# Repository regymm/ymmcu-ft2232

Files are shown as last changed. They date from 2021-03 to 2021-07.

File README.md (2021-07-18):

## YMMCU-FT2232HL

#### Function

Can be used as Xilinx JTAG downloader & USB-to-UART bridge simultaneously following [this](https://gist.github.com/rikka0w0/24b58b54473227502fa0334bbe75c3c1). 

Partly pin-to-pin compatible with the CJMCU FT232HL(the purple PCB one) and has a standard 2x7 JTAG connector. 

Main chips: FT2232HL(QFP64), ASM1117(3.3V, SOT89), 93LC56(SOP8). 

Micro-USB + Type-C(tested later so not shown on pic) connection. 

Made with Kicad. 

#### Gallery

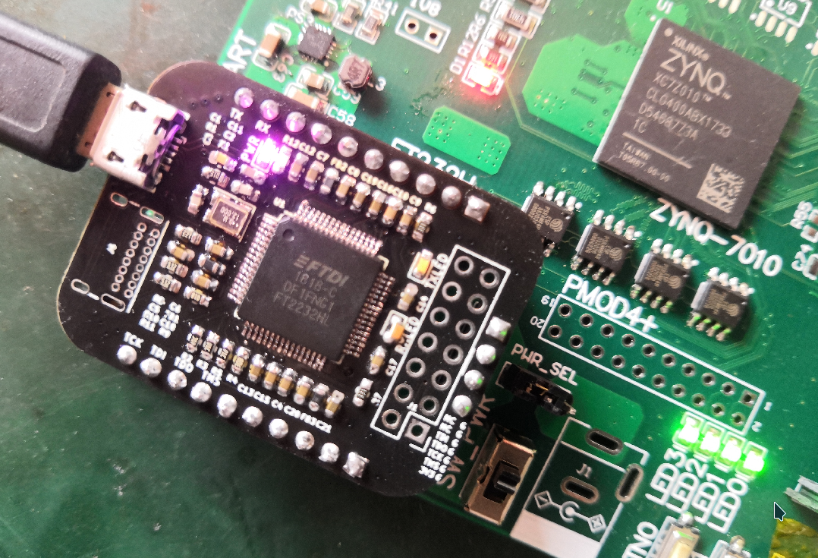
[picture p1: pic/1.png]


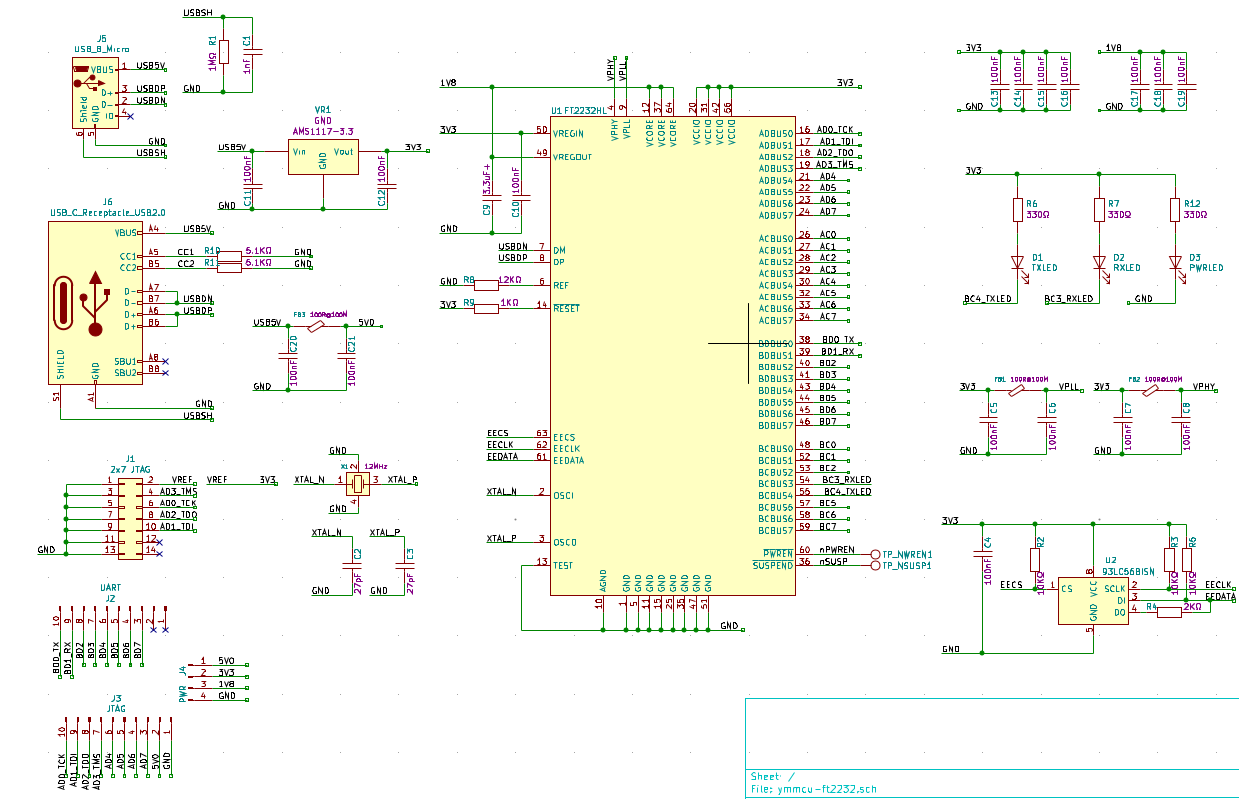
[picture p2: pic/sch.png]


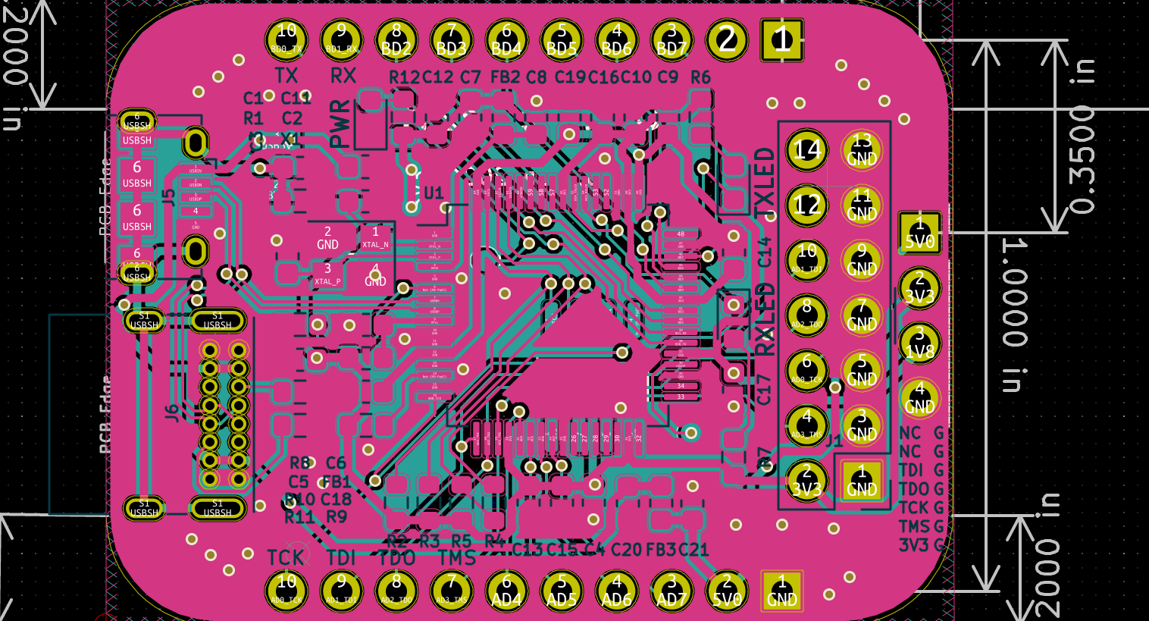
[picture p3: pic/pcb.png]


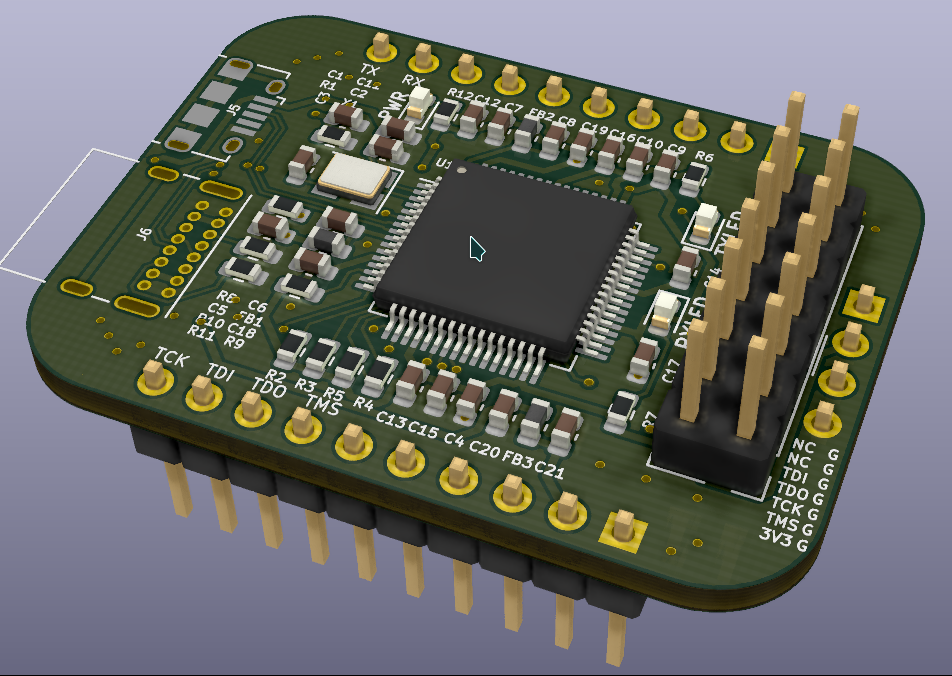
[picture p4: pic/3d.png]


#### License

GPL-v3

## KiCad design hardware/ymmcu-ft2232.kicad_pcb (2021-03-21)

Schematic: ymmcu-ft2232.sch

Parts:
C1: 0805_1nF__102_10%_50V; C_0603_1608Metric
C2, C3: 0805_27pF__270_5%_50V; C_0603_1608Metric
C4, C5, C6, C7, C8, C10, C11, C12, C13, C14, C15, C16, C17, C18, C19, C20, C21: 1206_100nF__104_10%_50V; C_0603_1608Metric
C9: 0805_3.3nF__332_10%_50V; C_0603_1608Metric
D1: TXLED; LED_0603_1608Metric
D2: RXLED; LED_0603_1608Metric
D3: PWRLED; LED_0603_1608Metric
FB1, FB2, FB3: FBEAD_SMD_BLM21PG221SN1D; L_0603_1608Metric
J1: 2x7 JTAG; PinHeader_2x07_P2.54mm_Vertical
J2: UART; PinHeader_1x10_P2.54mm_Vertical
J3: JTAG; PinHeader_1x10_P2.54mm_Vertical
J4: PWR; PinHeader_1x04_P2.54mm_Vertical
J5: USB_B_Micro; USB_Micro-B_Amphenol_10118194_Horizontal
J6: USB_C_Receptacle_USB2.0; USB_C_Receptacle_GCT_USB4085
R1: 0805_1MΩ__1004_1%; R_0603_1608Metric
R2, R3, R5: 1206_10KΩ__1002_1%; R_0603_1608Metric
R4: 1206_2KΩ__2001_1%; R_0603_1608Metric
R6, R7, R12: 0805_330Ω__3300_1%; R_0603_1608Metric
R8: 0805_12KΩ__1202_1%; R_0603_1608Metric
R9: 1206_1KΩ__1001_1%; R_0603_1608Metric
R10, R11: 0805_5.1KΩ__5101_1%; R_0603_1608Metric
TP_NSUSP1: TESTPOINT_SMD_C1; TestPoint_Pad_D1.0mm
TP_NWREN1: TESTPOINT_SMD_C1; TestPoint_Pad_D1.0mm
U1: FT2232HL; LQFP-64_10x10mm_P0.5mm
U2: 93LC56BISN; SOP-8_3.9x4.9mm_P1.27mm
VR1: SOT-223_AMS1117-3.3; SOT-223
X1: XTL_4_12MHz_3225; Crystal_SMD_3225-4Pin_3.2x2.5mm

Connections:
/1V8: C9.2, C17.2, C18.2, C19.2, J4.3, U1.12, U1.37, U1.49, U1.64
/3V3: C4.1, C5.1, C7.1, C10.2, C12.2, C13.2, C14.2, C15.2, C16.2, FB1.1, FB2.1, J1.2, J4.2, R2.1, R3.1, R5.1, R6.2, R7.2, R9.2, R12.2, U1.20, U1.31, U1.42, U1.50, U1.56, U2.8, VR1.2
/5V0: C21.1, FB3.2, J3.2, J4.1
/AD0_TCK: J1.6, J3.10, U1.16
/AD1_TDI: J1.10, J3.9, U1.17
/AD2_TDO: J1.8, J3.8, U1.18
/AD3_TMS: J1.4, J3.7, U1.19
/AD4: J3.6, U1.21
/AD5: J3.5, U1.22
/AD6: J3.4, U1.23
/AD7: J3.3, U1.24
/BC3_RXLED: D2.1, U1.54
/BC4_TXLED: D1.1, U1.55
/BD0_TX: J2.10, U1.38
/BD1_RX: J2.9, U1.39
/BD2: J2.8, U1.40
/BD3: J2.7, U1.41
/BD4: J2.6, U1.43
/BD5: J2.5, U1.44
/BD6: J2.4, U1.45
/BD7: J2.3, U1.46
/CC1: J6.A5, R10.1
/CC2: J6.B5, R11.1
/EECLK: R3.2, U1.62, U2.2
/EECS: R2.2, U1.63, U2.1
/EEDATA: R4.2, R5.2, U1.61, U2.3
/GND: C1.2, C2.2, C3.2, C4.2, C5.2, C6.2, C7.2, C8.2, C9.1, C10.1, C11.1, C12.1, C13.1, C14.1, C15.1, C16.1, C17.1, C18.1, C19.1, C20.2, C21.2, D3.1, J1.1, J1.3, J1.5, J1.7, J1.9, J1.11, J1.13, J3.1, J4.4, J5.5, J6.A1, J6.A12, J6.B1, J6.B12, R1.1, R8.1, R10.2, R11.2, U1.1, U1.5, U1.10, U1.11, U1.13, U1.15, U1.25, U1.35, U1.47, U1.51, U2.5, VR1.1, X1.2, X1.4
/USB5V: C11.2, C20.1, FB3.1, J5.1, J6.A4, J6.A9, J6.B4, J6.B9, VR1.3
/USBDN: J5.2, J6.A7, J6.B7, U1.7
/USBDP: J5.3, J6.A6, J6.B6, U1.8
/USBSH: C1.1, J5.6, J6.S1, R1.2
/VPHY: C8.1, FB2.2, U1.4
/VPLL: C6.1, FB1.2, U1.9
/XTAL_N: C2.1, U1.2, X1.1
/XTAL_P: C3.1, U1.3, X1.3
/nPWREN: TP_NWREN1.1, U1.60
/nSUSP: TP_NSUSP1.1, U1.36
unnamed: D1.2, R6.1
unnamed: D2.2, R7.1
unnamed: D3.2, R12.1
unnamed: R4.1, U2.4
unnamed: R8.2, U1.6
unnamed: R9.1, U1.14

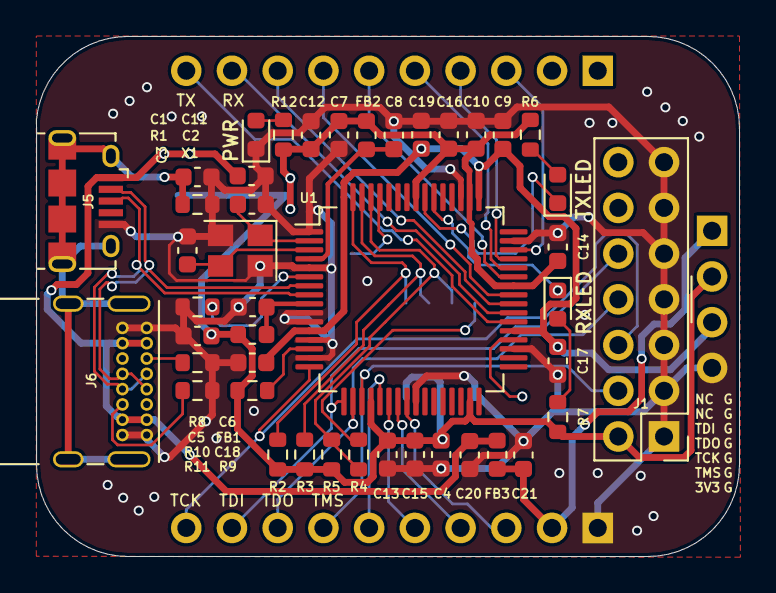
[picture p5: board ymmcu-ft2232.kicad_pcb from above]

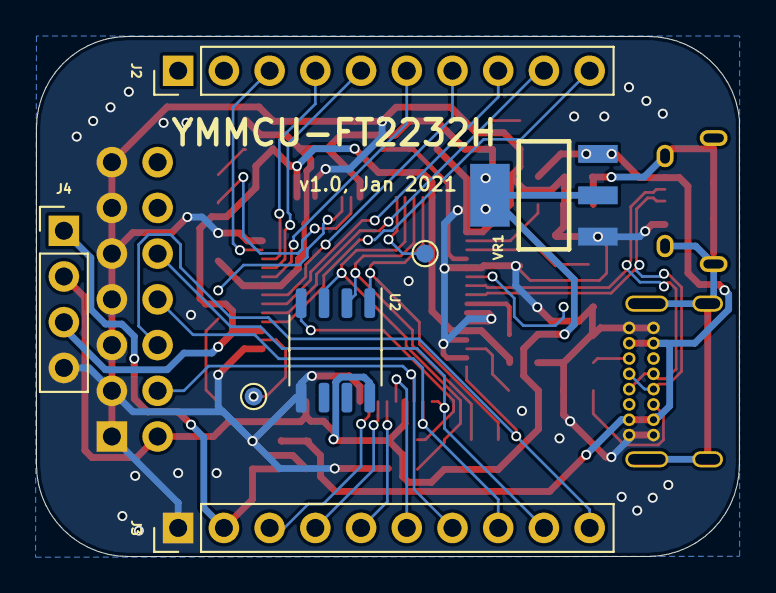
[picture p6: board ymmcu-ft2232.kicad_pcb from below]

Board: 2 copper layers, 39.1 x 28.9 mm, 51 parts (7 on the bottom side), 43 nets.
